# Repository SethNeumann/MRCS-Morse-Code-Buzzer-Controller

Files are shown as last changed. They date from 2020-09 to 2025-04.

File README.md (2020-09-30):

# REPO NAME: MRCS-Morse-Code-Buzzer-Controller
## License: Creative Commons Attribution-NonCommercial-ShareAlike

On many operations-oriented model railroads, particularly those which use time-table and train-order (TT&TO) or tower-based dispatching, 
there is a need to provide telephone communications between the dispatcher and the agent/operators. However, even on large model railroads
with multiple agent/operators, the physical distances between the operator positions are often insufficient to allow the operators to
reliably determine that “hey that’s my phone ringing.”

The Morse Code Buzzer Controller serves up to seven stations, tapping out each ringing station's Telegraph call sign in Railroad Morse.
An additional output can be designated an “ambience” buzzer that will randomly play one of several canned messages. These could be train
orders, news reports, or “inside jokes”

The board accepts push button inputs, stops when the phone goes off-hook (phone must have a suitable contact to provide an isolated ground 
or use the MRCS Off-Hook_Detector) and can drive loads of up to 0.5 Amp at up to 48 Volts DC.  All buzzer/sounder devices must use the same
supply.  Sounders must have have a coil resistance of greater than 40 ohms if using a 12V supply, or else use our Sounder Driver.

This version accepts 10-24 VDC from the MRCS telephone bus or a layout auxilliary supply or an external wall wart (not supplied)

The on-board Arduino Pro-Mini runs the "station buzzers" sketch by Steve Williams.  Please indicate the telegraph codes for your 
stations, unless you intend to load the sketch yourself.

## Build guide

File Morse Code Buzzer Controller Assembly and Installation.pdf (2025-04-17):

# Morse Code Buzzer Controller

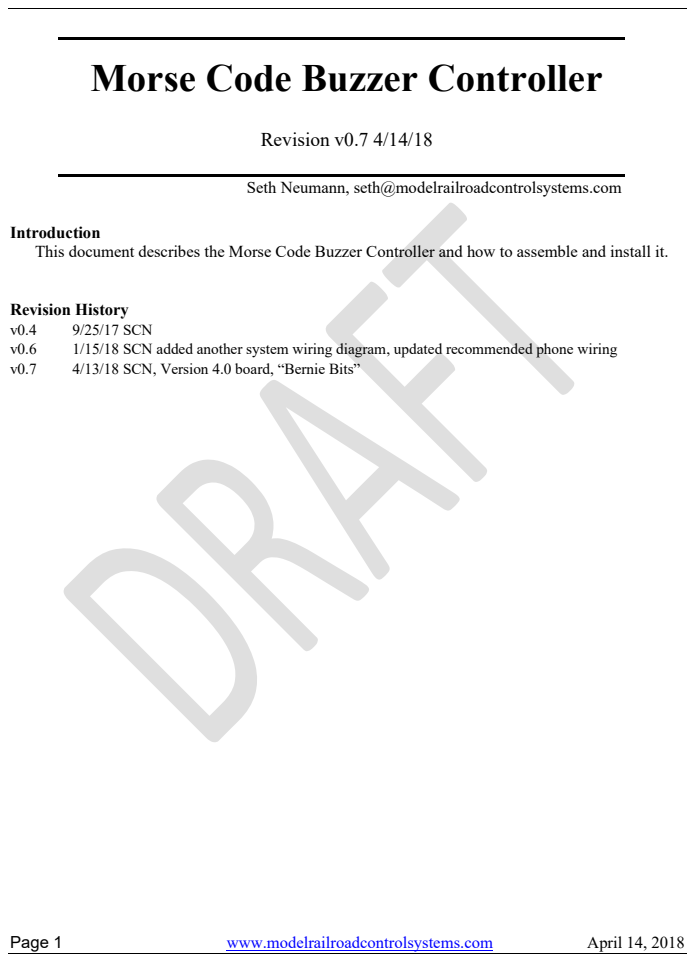
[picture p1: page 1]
Page 1; www.modelrailroadcontrolsystems.com; April 14, 2018; Revision v0.7 4/14/18; Revision History; 9/25/17 SCN; 1/15/18 SCN added another system wiring diagram, updated recommended phone wiring; 4/13/18 SCN, Version 4.0 board, “Bernie Bits”

Seth Neumann, seth@modelrailroadcontrolsystems.com

Introduction
This document describes the Morse Code Buzzer Controller and how to assemble and install it.

## Table of Contents

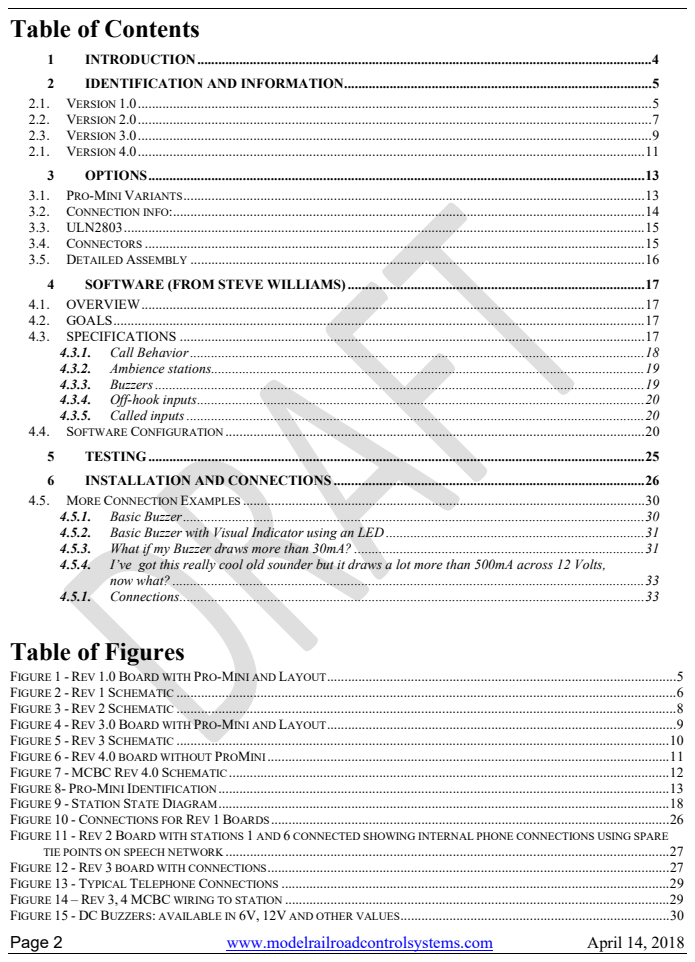
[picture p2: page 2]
Page 2; www.modelrailroadcontrolsystems.com; April 14, 2018; now what? ....................................................................................................................................... 33

1 INTRODUCTION .................................................................................................................................. 4
2 IDENTIFICATION AND INFORMATION ........................................................................................ 5
2.1. VERSION 1.0 ................................................................................................................................................... 5
2.2. VERSION 2.0 ................................................................................................................................................... 7
2.3. VERSION 3.0 ................................................................................................................................................... 9
2.1. VERSION 4.0 ................................................................................................................................................. 11
3 OPTIONS .............................................................................................................................................. 13
3.1. PRO-MINI VARIANTS .................................................................................................................................... 13
3.2. CONNECTION INFO:....................................................................................................................................... 14
3.3. ULN2803 ..................................................................................................................................................... 15
3.4. CONNECTORS ............................................................................................................................................... 15
3.5. DETAILED ASSEMBLY .................................................................................................................................. 16
4 SOFTWARE (FROM STEVE WILLIAMS) ..................................................................................... 17
4.1. OVERVIEW ................................................................................................................................................ 17
4.2. GOALS ........................................................................................................................................................ 17
4.3. SPECIFICATIONS ..................................................................................................................................... 17
4.3.1. Call Behavior .................................................................................................................................. 18
4.3.2. Ambience stations............................................................................................................................ 19
4.3.3. Buzzers ............................................................................................................................................ 19
4.3.4. Off-hook inputs ................................................................................................................................ 20
4.3.5. Called inputs ................................................................................................................................... 20
4.4. SOFTWARE CONFIGURATION ........................................................................................................................ 20
5 TESTING .............................................................................................................................................. 25
6 INSTALLATION AND CONNECTIONS ......................................................................................... 26
4.5. MORE CONNECTION EXAMPLES ................................................................................................................... 30
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

## Table of Tables

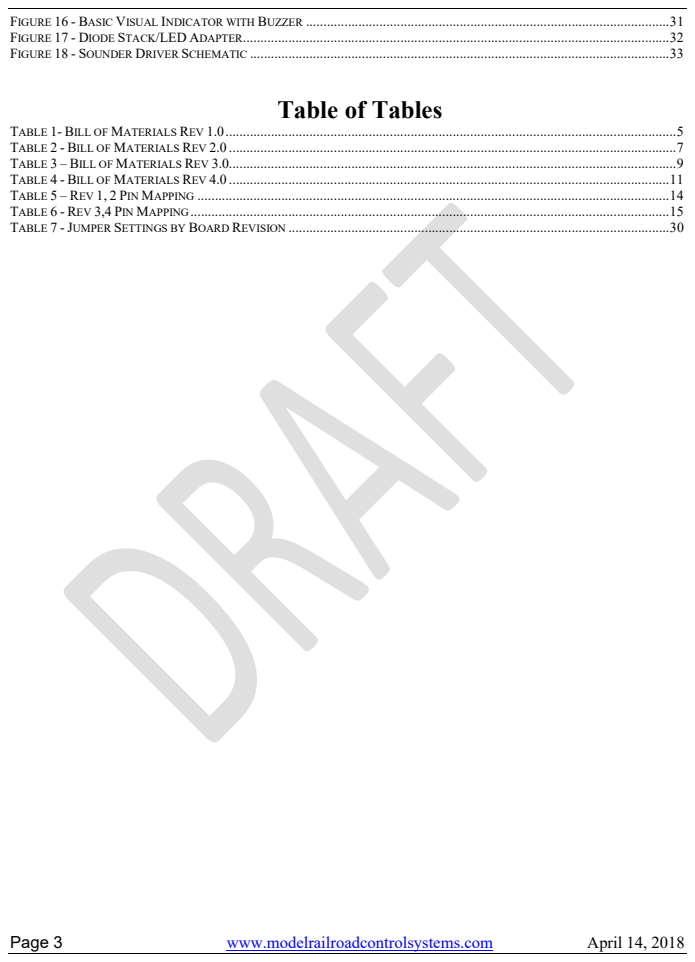
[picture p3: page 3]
Page 3; www.modelrailroadcontrolsystems.com; April 14, 2018

FIGURE 16 - BASIC VISUAL INDICATOR WITH BUZZER ........................................................................................................ 31
FIGURE 17 - DIODE STACK/LED ADAPTER .......................................................................................................................... 32
FIGURE 18 - SOUNDER DRIVER SCHEMATIC ........................................................................................................................ 33

TABLE 1- BILL OF MATERIALS REV 1.0 ................................................................................................................................. 5
TABLE 2 - BILL OF MATERIALS REV 2.0 ................................................................................................................................ 7
TABLE 3 – BILL OF MATERIALS REV 3.0................................................................................................................................ 9
TABLE 4 - BILL OF MATERIALS REV 4.0 .............................................................................................................................. 11
TABLE 5 – REV 1, 2 PIN MAPPING ....................................................................................................................................... 14
TABLE 6 - REV 3,4 PIN MAPPING ......................................................................................................................................... 15
TABLE 7 - JUMPER SETTINGS BY BOARD REVISION ............................................................................................................. 30

Page 4 | www.modelrailroadcontrolsystems.com | April 14, 2018

### 1 INTRODUCTION

This board is an Arduino Pro Mini breakout primarily designed to support Steve Williams’ “Station Buzzer” sketch. It also serves as a break out board for other applications.

- Rev 1 and 2 operate on 5 volts regulated DC, draws about 40 mA, Rev 3 uses 6-12 VDC regulated, wall wart, we recommend 7.5 – 9V to reduce the load on the on board regulator on the Pro-Mini
- Rev 1 and 2 support up to 6 stations (to use the 6th you must remove a resistor on the Pro-Mini by unsoldering)
- Each station uses two inputs and one output
- Inputs are active low* with on board pull ups, the output can sink up to .5 A at 50V DC (suitable for many sounders at 24V, but check the current draw on your sounder, you may need to use a “Sounder Driver” adapter if you expect to draw more than 0.5A)
- The Station Buzzers Sketch allows up to 7 stations to be active at any one time, but only one is buzzed at a time in order to keep the noise in the layout room reasonable and to allow operators to more accurately localize their buzzer/sounder.
- uses standard semiconductors available from Jameco and similar suppliers
- Rev 1 and 2 are based on a board that uses 6 analog capable inputs, 6 digital inputs ( or outputs) and 6 PWM capable outputs that are connected to Darlington Drivers capable of sinking up to .5A at 50V, with internal clamps. The board is also sutiable for projects such as using an analog pot to control a moderate current load with PWM (LED Lighting, Motor Control, etc). This arrangement limits the board to 6 circuits and requires modifying the Pro-Mini to use the 6th circuit.
- Rev 3 and 4 are optimized for Steve’s Station Buzzers Sketch and supports up to 7 circuits plus and an “ambience” output which randomly plays a selection of user-entered messages at random intervals. No modification of the Pro-Mini is required but there are several footprints of Pro-Minis around so be sure you use a board with enhanced Sparkfun footprint. Almost all of these are compatible on at least the first 4 circuits.

* These defaults can be changed by modifying the sketch, -- see “Software” below

All components are through-hole technology for ease of assembly and repair.

Input connection pads are standardized on .100” centers. This provides a wide range of interconnect options and components. Connection schemes include screw terminal blocks, header pin connectors (male and female), soldered right angle headers, and direct soldered wires.

Outputs are on 3.5mm connectors to handle larger wires for more current.

Power can be supplied on either a 2.1mm center positive barrel connector or a 5mm terminal block. A separate 5mm terminal block is provided for load ground and supply (if you intend to use the internal clamp diodes).

Page 5 | www.modelrailroadcontrolsystems.com | April 14, 2018

### 2 IDENTIFICATION AND INFORMATION

2.1.VERSION 1.0

Figure 1 - Rev 1.0 Board with Pro-Mini and Layout

The Revision 1.0 board has some issues with labels not aligning properly and was shipped with label tape over the board labels. These were all green. They can also be distinguished by the vertical line of 6 pads (not stuffed) next to the “FTDI header” label. These boards support up to 6 stations and, for the hackers, have start (“called” in the sketch) leads on Analog capable inputs. A separate 5mm jack is provided for output ground and for a connection to the load supply so the clamp diodes in the ULN2803 Darlington driver will protect the outputs. Using the 6th circuit requires removing the resistor for D13 from the Arduino Pro-Mini. This board uses 5VDC regulated power.

A quantity of zero denotes an alternate component or a component that may be used in a particular configuration.

Table 1- Bill of Materials Rev 1.0

Qty | Value | Device | Parts | Description | Vendor | Part #
2 .1 uF @ 50V | | C-US025-030X050 | C1, C3 | Cap, monolithic | Jameco | 25523
1 100 uF @ 50V | | CPOL-USE3.5-10 | C2 | POLARIZED CAPACITOR, American symbol | Jameco | 29962
2 | 1751264 4 PositionHeader | | J1, J2 | MKDS 1/ 4-3,5 Printklemme | Jameco | 212411
1 ARDUINO_PRO_MINI | | ARDUINO_PRO_MINI | U$2 | | eBay
1 DIODE_1N5819-B | | DIODE_1N5819-B | D1 | 1.0A SCHOTTKY BARRIER RECTIFIER | Jameco | 177965
1 Power | | CONNECTOR-DC-POWER-RA | CON3 | DC POWER JACK | Jameco | 101178
2 Power, load | | CONNECTOR-M02508-LOCK | CON4,5 | PHOENIX CONNECTOR | Jameco | 2094485
1 RAW/5V | | JUMPER-3PTH-LOCK | JP2,3,4 | | Banggood
2 12 pos 0.100 female | | 12 pos 0.100 female | JP5,6 | for arduino | Pololu | 1030
1 2 pos 0.100 female | | 2 pos 0.100 female | JP7,8 | for arduino | Pololu | 1012
1 jumper plug | | for JP 2,3,4 | jmp | power, D0, D1 | Jameco | 112432
2 Start,stop Leads | | CONNECTOR-M08LOCK | CON1,2 | Header 6 (only 6 positions used for ncb) | E-Salon
1 ULN2803 | | ULN2803A | IC1 | DRIVER ARRAY | Jameco | 34315
1 18 pin socket | | 18 pin socket | socket | socket 18 | Jameco | 112231
1 short | | M02LOCK | JP4 | Standard 2-pin 0.1 header. Use with" | Banggood
1 board 69x100 mm | | New Coded Buzzer | | Board | Seeed

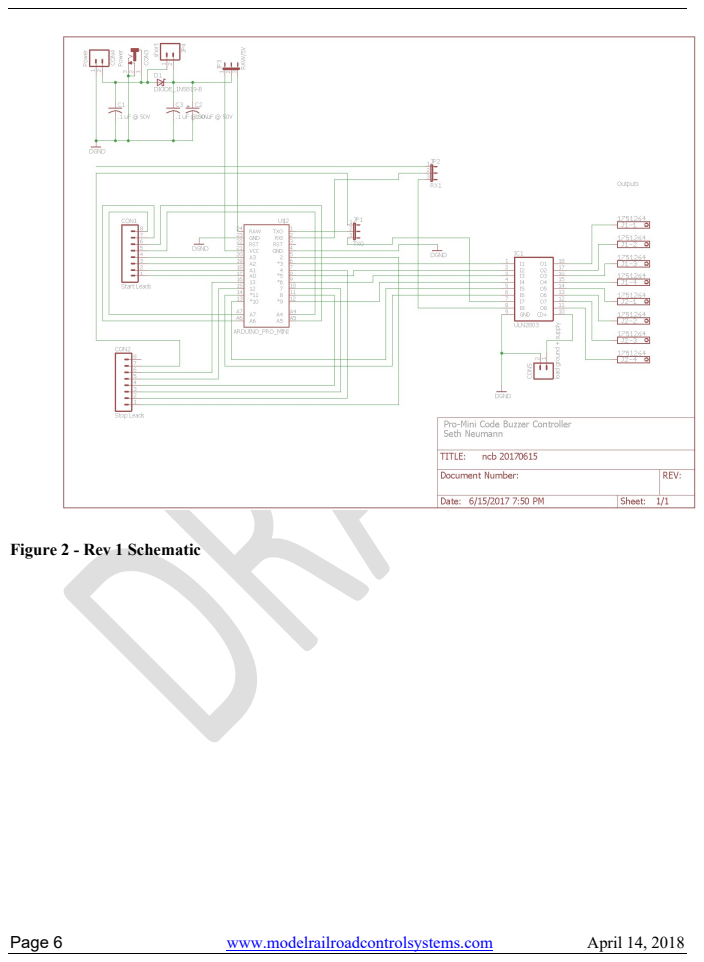
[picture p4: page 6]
Page 6; www.modelrailroadcontrolsystems.com; April 14, 2018

Figure 2 - Rev 1 Schematic

Page 7 | www.modelrailroadcontrolsystems.com | April 14, 2018

2.2.VERSION 2.0

The Revision 2.0 board was redrawn by John Plocher and the layout is optimized, and the labels and legends have been corrected. These were all on white PCBs and have 2.0 20170714 printed on the upper right. The inputs are configured the same Rev 1.0. The power connector has been rotated and placed so that you can either use the 2.1mm barrel jack or a 5mm power connector, not both. A separate 5mm jack is provided for output ground and for a connection to the load supply so the clamp diodes in the ULN2803 Darlington driver will protect the outputs. We are now shipping the Rev 3 configuration, but if you want to order this board (for an A/D project) we can make them. Using the 6th circuit, requires removing the resistor for D13 from the Arduino Pro-Mini. This board uses 5VDC regulated power.

A quantity of zero denotes an alternate component or a component that may be used in a particular configuration.

Table 2 - Bill of Materials Rev 2.0

Qty | Value | Device | Parts | Description | Vendor | Part #
1 .1 uF @ 50V | | C-US025-030X050 | C3 | Cap, monolithic | Jameco | 25523
1 100 uF @ 50V | | CPOL-USE3.5-10 | C2 | POLARIZED CAPACITOR, American symbol | Jameco | 29962
1 | 1751264 4 Position 3.5mm screw terminal | | J1, J2 | MKDS 1/ 4-3,5 Printklemme | Jameco | 212411
1 2 Position 3.5mm screw terminal
1 ARDUINO_PRO_MINI | | ARDUINO_PRO_MINI | U$2 | | eBay
1 Power | | CONNECTOR-DC-POWER-RA | CON3 | DC POWER JACK | Jameco | 101178
2 Power, load | | CONNECTOR-M02508-LOCK | CON4,5 | PHOENIX CONNECTOR | Jameco | 2094485
0 RAW/5V | | JUMPER-3PTH-LOCK | JP2,3,4 | | Banggood
2 12 pos 0.100 female | | 12 pos 0.100 female | JP5,6 | for arduino | Pololu | 1030
1 2 pos 0.100 female | | 2 pos 0.100 female | JP7,8 | for arduino | Pololu | 1012
0 jumper plug | | for JP 2,3,4 | jmp | power, D0, D1 | Jameco | 112432
2 Start,stop Leads | | CONNECTOR-M08LOCK | CON1,2 | Header 6 (only 6 positions used for ncb) | E-Salon
1 ULN2803 | | ULN2803A | IC1 | DRIVER ARRAY | Jameco | 34315
1 18 pin socket | | 18 pin socket | socket | socket 18 | Jameco | 112231
0 short | | M02LOCK | JP4 | Standard 2-pin 0.1 header. Use with" | Banggood
1 board 69x100 mm | | New Coded Buzzer | | Board | Seeed

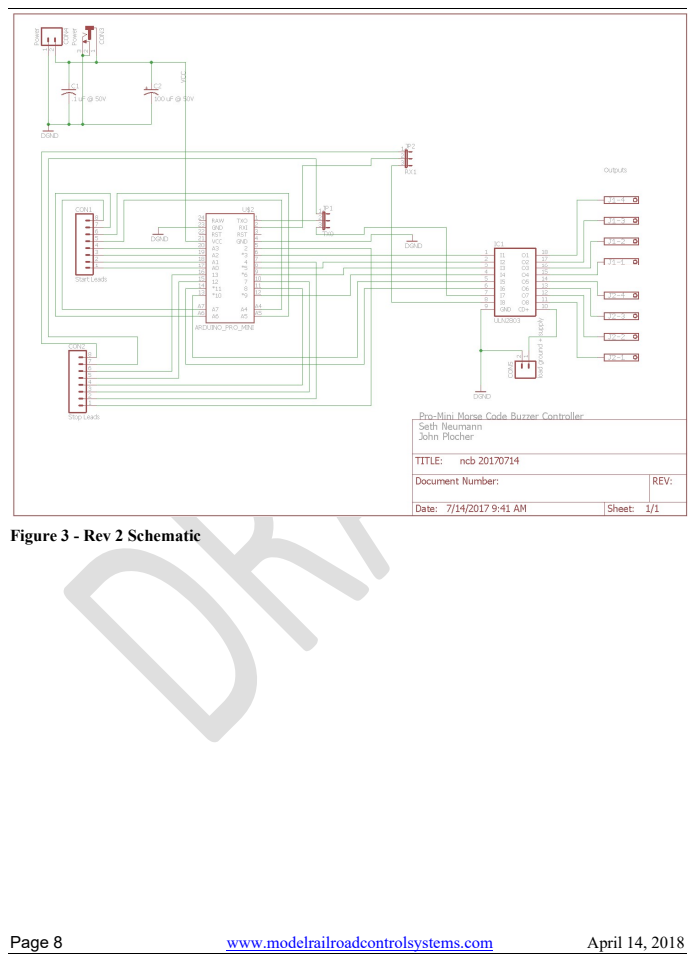
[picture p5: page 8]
Page 8; www.modelrailroadcontrolsystems.com; April 14, 2018

Figure 3 - Rev 2 Schematic

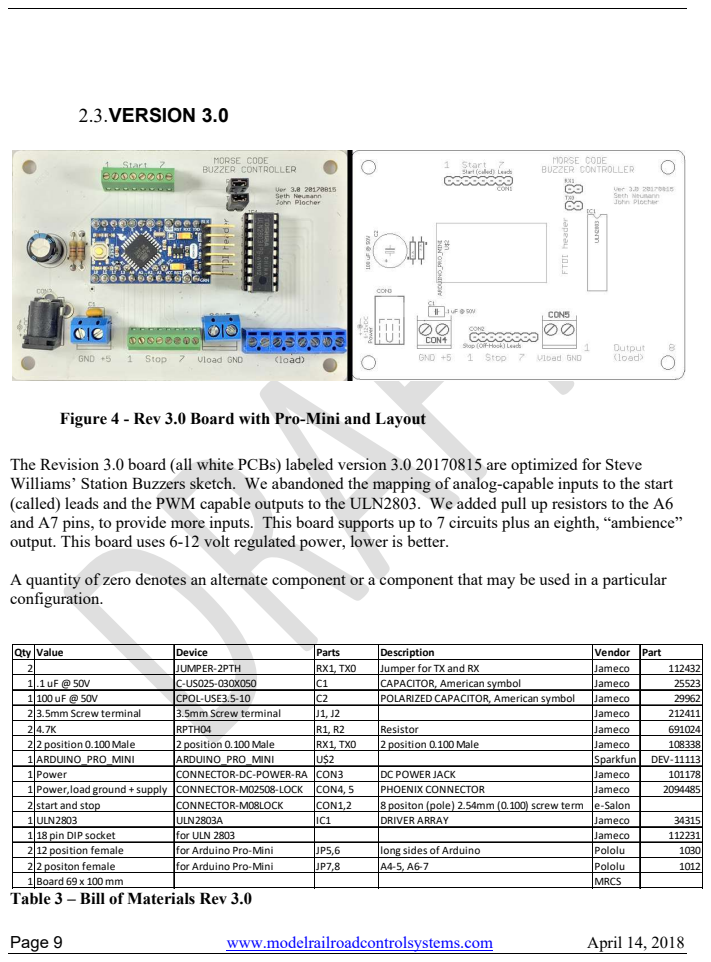
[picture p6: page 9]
Page 9; www.modelrailroadcontrolsystems.com; April 14, 2018; 2.3.VERSION 3.0

Figure 4 - Rev 3.0 Board with Pro-Mini and Layout

The Revision 3.0 board (all white PCBs) labeled version 3.0 20170815 are optimized for Steve
Williams’ Station Buzzers sketch. We abandoned the mapping of analog-capable inputs to the start
(called) leads and the PWM capable outputs to the ULN2803. We added pull up resistors to the A6
and A7 pins, to provide more inputs. This board supports up to 7 circuits plus an eighth, “ambience”
output. This board uses 6-12 volt regulated power, lower is better.

A quantity of zero denotes an alternate component or a component that may be used in a particular
configuration.

Qty | Value | Device | Parts | Description | Vendor | Part
2 | | JUMPER-2PTH | RX1, TX0 | Jumper for TX and RX | Jameco | 112432
1 .1 uF @ 50V | | C-US025-030X050 | C1 | CAPACITOR, American symbol | Jameco | 25523
1 100 uF @ 50V | | CPOL-USE3.5-10 | C2 | POLARIZED CAPACITOR, American symbol | Jameco | 29962
2 3.5mm Screw terminal | | 3.5mm Screw terminal | J1, J2 | | Jameco | 212411
2 4.7K | | RPTH04 | R1, R2 | Resistor | Jameco | 691024
2 2 position 0.100 Male | | 2 position 0.100 Male | RX1, TX0 | 2 position 0.100 Male | Jameco | 108338
1 ARDUINO_PRO_MINI | | ARDUINO_PRO_MINI | U$2 | | Sparkfun | DEV-11113
1 Power | | CONNECTOR-DC-POWER-RA | CON3 | DC POWER JACK | Jameco | 101178
1 Power,load ground + supply | | CONNECTOR-M02508-LOCK | CON4, 5 | PHOENIX CONNECTOR | Jameco | 2094485
2 start and stop | | CONNECTOR-M08LOCK | CON1,2 | 8 positon (pole) 2.54mm (0.100) screw term | e-Salon
1 ULN2803 | | ULN2803A | IC1 | DRIVER ARRAY | Jameco | 34315
1 18 pin DIP socket | | for ULN 2803 | | | Jameco | 112231
2 12 position female | | for Arduino Pro-Mini | JP5,6 | long sides of Arduino | Pololu | 1030
2 2 positon female | | for Arduino Pro-Mini | JP7,8 | A4-5, A6-7 | Pololu | 1012
1 Board 69 x 100 mm | | | | | MRCS

Table 3 – Bill of Materials Rev 3.0

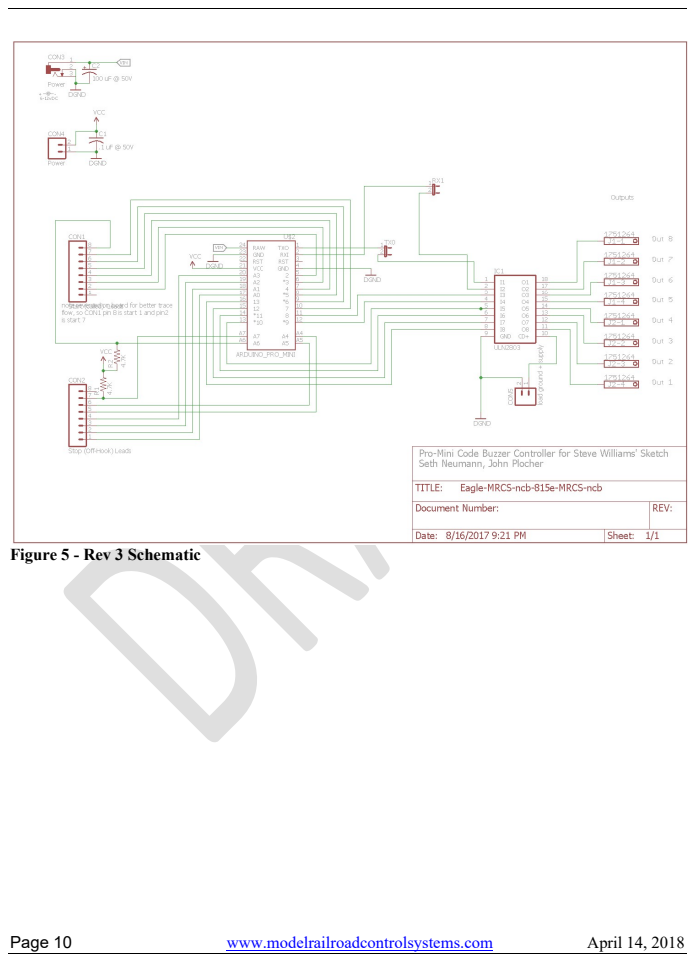
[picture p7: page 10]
Page 10; www.modelrailroadcontrolsystems.com; April 14, 2018

Figure 5 - Rev 3 Schematic

Page 11 | www.modelrailroadcontrolsystems.com | April 14, 2018

2.1.VERSION 4.0

Figure 6 - Rev 4.0 board without ProMini

The Revision 4.0 board (all white PCBs) labeled version 4.0 2018.0302 are optimized for Steve Williams’ Station Buzzers sketch. Rev 4 follows the Rev 3 mapping and adds flexibility on the Vout connector, CON4. This board uses 6-12 volt regulated power, lower is better as there is less stress on the regulator. Allow 25mA for the Arduino itself and 125mA of Vcc (of a total 150mA) is available if JP1 is set for 5V. The combination of JP1 and JP2 allow you to do any of the following:
- Source up to 125 mA of regulated 5VDC from Vout, for low voltage audible alerts such as piezo-electric sounders.
- Source the input voltage on the barrel jack to the Vout and clamp that supply voltage to the clamp diodes in the ULN2803. For example a 12V 1A supply could supply 12V buzzers (actually very little current here as only one device buzzes at a time) or even a fairly high impedance sounder (be sure to clamp inductive loads).
- Set to 5V, you can source regulated 5VDC to the Arduino by the Vout connector. DO NOT attempt to supply an input voltage higher than 5V as it will destroy the Arduino.
Qty | Value | Device | Package | Parts | Description
3 | | JUMPER-2PTH | 1X02 | JP2, RX1, TX0 | Jumpers RX, TX and Clamp
1 | | M03LOCK | 1X03_LOCK | JP1 | Header 3
1 .1 uF @ 50V | | C-US025-030X050 | C025-030X050 | C1 | CAPACITOR, American symbol
1 100 uF @ 50V | | CPOL-USE3.5-10 | E3,5-10 | C2 | POLARIZED CAPACITOR, American symbol
2 3.5mm screw term | | 3.5mm screw term | 3.5mm screw term | J1, J2 | 3.5mm screw term
2 4.7K | | RPTH04 | AXIAL-0.4-RES | R1, R2 | Resistor 1/4 Watt
1 ARDUINO_PRO_MINI | | ARDUINO_PRO_MINI | ARDUINO_PRO_MINI | U$2 | Sparkfun enhanced Style
1 Power | | CONNECTOR-DC-POWER-RA | DCJ0202 | CON3 | DC POWER JACK 2.1x5
2 Power | | CONNECTOR-M02508-LOCK | MSTB2 | CON4,5 | PHOENIX CONNECTOR
2 0.100 x 8 | | CONNECTOR-M08LOCK | 1X08_LOCK | CON1,2 | Header 8
1 ULN2803 | | ULN2803A | DIL18 | IC1 | DRIVER ARRAY
1 18 pin DIP Socket | | 18 pin DIP Socket | DIL18 | socket | 18 pin DIP Socket
2 12 pin 0.100 socket | | 12 pin 0.100 socket | 12 pin 0.100 socket | socket | long sockets for Arduino
2 2 pin 0.100 socket | | 2 pin 0.100 socket | 2 pin 0.100 socket | socket | Short sockers for A4,5 and A6,7

Table 4 - Bill of Materials Rev 4.0

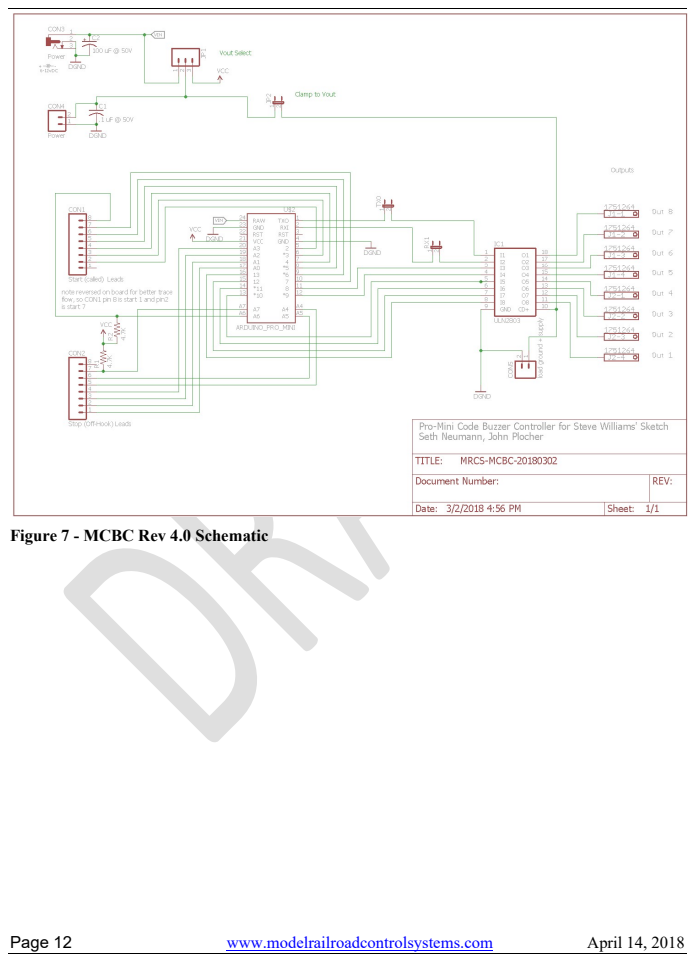
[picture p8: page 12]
Page 12; www.modelrailroadcontrolsystems.com; April 14, 2018

Figure 7 - MCBC Rev 4.0 Schematic

Page 13 | www.modelrailroadcontrolsystems.com | April 14, 2018

### 3 OPTIONS

3.1.PRO-MINI VARIANTS

The Pro-Mini was developed by Sparkfun www.sparkfun.com as a small, inexpensive alternative to Uno and Leonardo using surface mount technology and eliminating the USB port, in favor of an FTDI interface. You will need an FTDI cable or converter to program the promini. These are inexpensive and can be found at Speakfun, Adafruit and many inexpensive off-shore outlets.
There are several alternative footprints to the pro-mini. We use the revised Sparkfun version which has two rows of 12 pins along the long sides, a 6 pin FTDI header at one end and two sets of two off set pins for A4-A5 and A6-A7. If you get your Pro-Mini from Sparkfun, just go ahead and add 0.100 headers to the long sides and off set pins. One of the other designs has A4-5 in the off set position and A6-7 on the end opposite the FTDI header, the other has A4-7 on the opposite end. Be sure you’ve got the one you need. If you are not using all 7 positions you won’t need all of the A(4-7) inputs, so check your requirements and you may be able to use the other footprints.
As noted above all the analog (A0 through A7) are used as inputs. Since these inputs are capable of A to D conversion, I’ve kept them separate for use in other projects on Rev 1 and 2. The outputs D3,5,6,9,10 and 11 are PWM capable, and since PWM is an output function, I’ve kept them together on Rev 1 and 2. The stop inputs use the non-PWM digital pins remaining starting with D2 on Rev 1 and 2 boards. D0 and D1 are Rx and TX respectively and they are connected by three position jumpers to either outputs six and seven or stop lines 6 and seven or they can be left open if not otherwise used. The jumpers should be removed while programming. On Rev 3 boards the mapping has changed (see configuration below) to allow up to 7 circuits.

Figure 8- Pro-Mini Identification

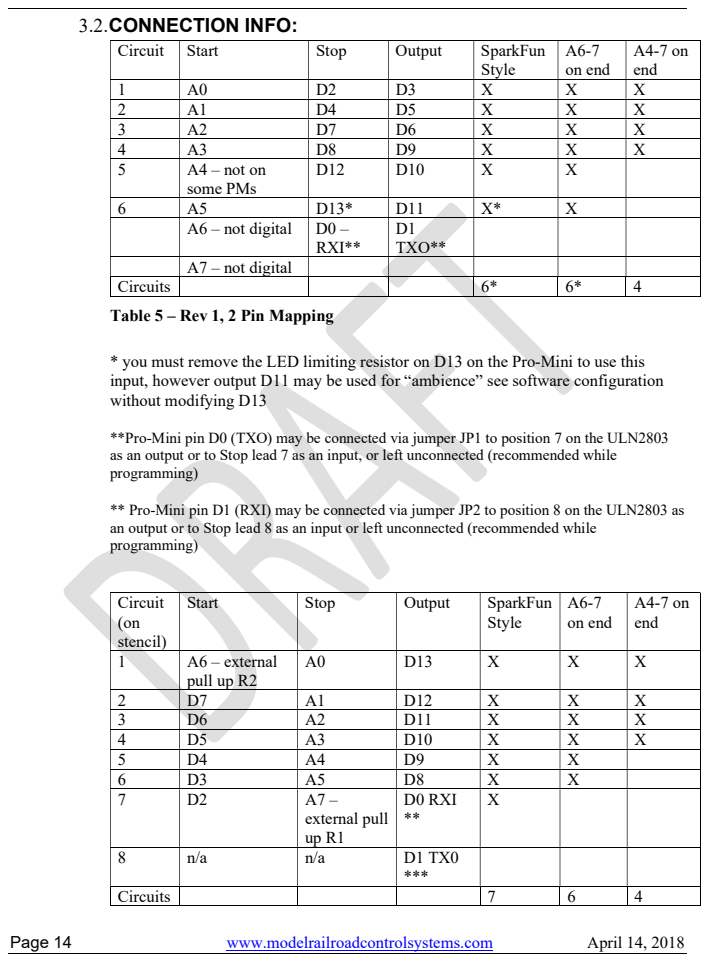
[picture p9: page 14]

Circuit | Start | Stop | Output | SparkFun Style | A6-7 on end | A4-7 on end

1 | A0 | D2 | D3 | X | X | X
2 | A1 | D4 | D5 | X | X | X
3 | A2 | D7 | D6 | X | X | X
4 | A3 | D8 | D9 | X | X | X
5 A4 – not on | some PMs | D12 | D10 | X | X

A6 – not digital | D0 – RXI** | D1 TXO**

A7 – not digital

Circuits | | | | 6* | 6* | 4

Table 5 – Rev 1, 2 Pin Mapping

* you must remove the LED limiting resistor on D13 on the Pro-Mini to use this
input, however output D11 may be used for “ambience” see software configuration
without modifying D13

**Pro-Mini pin D0 (TXO) may be connected via jumper JP1 to position 7 on the ULN2803
as an output or to Stop lead 7 as an input, or left unconnected (recommended while
programming)

** Pro-Mini pin D1 (RXI) may be connected via jumper JP2 to position 8 on the ULN2803 as
an output or to Stop lead 8 as an input or left unconnected (recommended while

Circuit (on stencil) | Start | Stop | Output | SparkFun Style | A6-7 on end | A4-7 on end

1 A6 – external | pull up R2 | A0 | D13 | X | X | X

2 | D7 | A1 | D12 | X | X | X
3 | D6 | A2 | D11 | X | X | X
4 | D5 | A3 | D10 | X | X | X
5 | D4 | A4 | D9 | X | X
6 | D3 | A5 | D8 | X | X
7 | D2 | A7 – external pull up R1 | D0 RXI ** | X

Circuits | | | | 7 | 6 | 4

Page 15 | www.modelrailroadcontrolsystems.com | April 14, 2018

Table 6 - Rev 3,4 Pin Mapping

**Pro-Mini pin D0 (TXO) may be connected via jumper JP1 to position 7 on the ULN2803 as an output or to Stop lead 7 as an input, or left unconnected (recommended while programming)

*** Pro-Mini pin D1 (RXI) may be connected via jumper JP2 to position 8 on the ULN2803 as an output or to Stop lead 8 as an input or left unconnected (recommended while programming). It is recommended that you use TXO if you want to employ the “ambience” function.

3.3.ULN2803

The ULN2803 is a high current driver that can sink up to 0.5A at up to 50V on each output. We included it because the lead users wanted to drive telegraph sounders, which operate at 24-48 volts, and the Pro-Mini is limited to 5V (and 25 mA). If you will only be driving logic level loads, you can omit the ULN2803 and wire across the pins for the socket. If you are using a Rev 1 or 2 board for motor or high current LED control, you’ll want to use the ULN2803. We recommend socketing the ULN2803 because it lives in a rough neighborhood and may need replacement.

3.4.CONNECTORS

- The input connectors are on 0.100 centers (staggered slightly to hold the connectors in place during assembly). While our standard connector is the 0.100 screw terminal, you may substitute any other 0.100 connector you prefer. If ordering an assembled and tested unit from MRCS and you would prefer a different connector, please contact us at sales@modelrailroadcontrolsystems.com and indicate your preference and we’ll provide a quotation.
- Output connectors are 3.5mm screw terminals. Again you can substitute any 3.5mm pitch connector.
- We provided a 2.1 mm, center positive, barrel jack for power, Rev 1 and 2 use 5V, Rev 3 and

### 4 use 6-12 volts. Be careful and check the output of your power supply, overvoltage will

kill the Pro-Mini. The 5mm pitch screw terminal block parallels the barrel jack (Rev1,2) but in Rev 3 the 5V is the output of the Pro-Mini’s regulator. In Rev 4 the 5V is replaced by a Vout pin which can be jumper selected to either 5V from the regulator (keep your loads to a total of 100 mA) or the voltage from the barrel jack.

- The last connector is a 5mm screw terminal for referencing the output loads (buzzer, sounder etc.) Connect the ground to the ground of the supply powering the outputs (don’t worry about this if running low current/low voltage buzzers off the Morse Code Buzzer Controller’s supply). Connect the positive side of the load supply to the screw marked “LD” or “LOAD” This provides a reference for the clamp diodes in the ULN2803 that protects it from inductive spikes.

Page 16 | www.modelrailroadcontrolsystems.com | April 14, 2018

3.5.DETAILED ASSEMBLY
[ ] All of the components are through-hole technology with wire leads. A useful tool is a lead bender for forming the leads at 90 degrees for easy insertion into the pad holes. Start with inserting the lower height components. The general rule is install the lowest components first, working towards components that are higher off the board. This enables you to support the low components as you solder them.

[ ] Resistors, Diodes
[ ] Install Resistors R1 and R2 (Rev 3 only) on the center left of the boards. Try to keep the gold tolerance band on the same side for easier reading of values.
[ ] Install diodes D1 (Rev 1.0 only). Observe polarity – band towards edge of board.

[ ] Monolithic Capacitors

[ ] Install C1,C3 (C3 on Rev 1.0 only) on left edge of board

[ ] IC Socket (if you are using the ULN2803)
[ ] Socket for IC1 – notch in socket pointing up

[ ] Electrolytic Capacitors
[ ] Install C2 last as it is the highest component on the board. Observe polarity: stripe to the right.

[ ] Arduino Sockets – these come in various heights, so compare height off board with other components.

[ ] Option Headers
[ ] Install JP1,2,3,4 (Rev 1.0, Rev 4.0 ), JP1,2 (Rev 2.0, Rev 3.0),

[ ] Screw Terminals and Power Jack
[ ] Install Con3 (2.1 mm barrel jack) unless you will not be using a 2.1mm plug to power your Morse Code Buzzer Controller
[ ] Install Con1 and Con2
[ ] Install Con4 unless you will be using Con3
[ ] Install Con5

[ ] Electronics

[ ] Install the ULN2803 if you are planning to use high current or high voltage (>5V) loads [ ] Install the Pro-Mini

[Pro-Mini]

Most pro-Minis come with male headers, if not you will need to supply them. I use the board as a fixture to hold the headers in place. Just put the headers into the socket and then gently wiggle the Pro-Mini so it sits down tight and solder the end pins on each header. Then check for alignment, it’s easy to adjust with just one pin on each end soldered, a quick re-melt will do.

Page 17 | www.modelrailroadcontrolsystems.com | April 14, 2018

### 4 SOFTWARE (FROM STEVE WILLIAMS)

### 4.1. OVERVIEW

On many operations-oriented model railroads, particularly those which operate under a timetable and train-order (TT&TO) or tower-based dispatching system, there is a need to provide telephone communications between the dispatcher and the agent/operators. However, even on fairly large model railroads with multiple agent/operators, the physical distances between the operator positions are often insufficient to allow the operators to reliably distinguish that “hey that’s my phone ringing.”

This document describes the design of the “station_buzzzers” Arduino script which controls the buzzers on a model railroad telephone system to play the called station’s timetable station call-sign in American Railroad Morse code, and to cycle among the called stations so that only one buzzer is sounding at a time. Model Railroad Control Systems has developed a companion “Morse Code Buzzer Board” which provides convenient connections to an Arduino Pro-Mini running the station_buzzers sketch.

### 4.2. GOALS

1. Provide separate “buzzer pins” for each station. Each pin can be made active HIGH or active LOW as needed depending on the external buzzer driver circuits used. The Morse Code Buzzer Controller uses an active high output to activate it’s Darlington output which provides a ground to operate a load of up to 0.5A at up to 50V.

### 2. Provide support for “ambience” buzzers that will randomly play one of several canned

messages. These could be train orders, news reports, or “inside jokes”.
3. Provide separate “answered” inputs for each station with individual control of the active HIGH or LOW level for the input. The Morse Code Buzzer Controller assumes a low input, but you can change it in this sketch.
4. Provide separate “called” input pins for each with individual control of the HIGH or LOW.
a. Each “called” input should also have individual selection between “momentary” versus “continuous”mode. For “continuous” mode, the station’s call-sign will continue to play until either the station is answered or the caller hangs up. For “momentary” stations, the station will start ringing after a momentary button press and continue ringing until answered or after a timeout. The Morse Code Buzzer Controller assumes a low input, but you can change it in this sketch.
5. Only allow one station buzzer to play at a time. When multiple stations are being called simultaneously, cycle through them playing each station’s call-sign with a couple of seconds delay between the end of one call-sign and the beginning of the next. This provides temporal as well as spatial separation of the station call-signs.

### 4.3. SPECIFICATIONS

Configuration of the list of station's, their call-signs, and operating modes will be done through a C++ structure array.

Page 18 | www.modelrailroadcontrolsystems.com | April 14, 2018

### 4.3.1. Call Behavior

The basic call flow for a single station is shown in the flow chart below.

Figure 9 - Station State Diagram

The states that each station runs through are:

IDLE -- both called and off_hook are deasserted

RING_WAITING -- the station has been called, but not yet answered. Stations enter this state before they are selected to ring. Stations entering RING_WAITING state set their last_ring_millis value to the current millis(), but stations entering from IDLE subtract 60 seconds so that they will look artificially old to the “selected_to_ring” logic

RING_PLAYING -- the station has been called and not answered and has been selected to ring. Only one station can be in the RING_PLAYING state at a time, and typically it will stay there until the Morse code for the station call-sign finishes playing one time. The selection of which station should ring is done by choosing the station which has been in the RING_WAITING state the longest.

TALKING -- the station is off-hook. We don't make a distinction between whether we got here directly from IDLE (station-initiated call) or from one of the RING_WAITING or RING_PLAYING states. For “momentary” stations, immediately upon entering TALKING, the called input is cleared and the station will transition to HANGUP_WAIT state.

Page 19 | www.modelrailroadcontrolsystems.com | April 14, 2018

HANGUP_WAIT -- one or the other sides has hung up and we are waiting for both sides to hang up.

The same basic flow applies to stations that use either “momentary” or “continuous” called inputs. All that is different is how the various “called” and “off_hook” methods behave.

### 4.3.2. Ambience stations

The sketch will also support defining one or more “ambience” stations. These are intended to be used for extra “audio candy” in the layout room. Each “ambience” station has a pointer to a table of message strings, and will randomly play one these messages each time it wakes up. The strings themselves will be stored in the Arduino’s flash (program) memory to allow a larger number of longer messages than just the typical one or two character station call-signs. The wake up interval will be randomly selected between a minimum and maximum interval.

Upon entry to IDLE state, an ambience station will choose the next string to play and the time in millis() at which to play it. When the designated time comes, the ambience station will transition to RING_WAITING. The choose_next_ringer selection logic will only allow an ambience station to transition RING_WAITING -> RING_PLAYING if all “regular” stations are in state IDLE.

If the sketch defines more than one ambience station, each ambience station will individually choose its random start time and which message to play next. If a another ambience station is playing when this station becomes ready to play, the sketch will let the first station’s message complete before starting the second. Internally, this is done through the normal IDLE -> RING_WAITING -> RING_PLAYING -> IDLE state sequence.

Any regular station leaving state IDLE (being called or going off-hook) will immediately force any ambience station in state RING_PLAYING back to state IDLE, terminating the current ambience message, resetting the random timers and making a new message choice. The thinking here is that the ambience buzzer may be playing a longer message that could distracting, so it is better to shut it off immediately.

Similarly, if any of the regular stations leaves state IDLE while any ambience station(s) are in RING_WAITING state, the ambience stations will stay RING_WAITING until all of the regular stations return to state IDLE (i.e. all calls are ended) before becoming eligible to play. It seems appropriate to give force the next ringer selection logic to wait a bit longer before allowing the ambience to resume, so there will be a separate timer to keep “ambience” messages farther apart.

### 4.3.3. Buzzers

We have used this sketch to drive a variety of sound-generating hardware from piezo-electric buzzers to relay-based telegraph sounders. In a quiet room, it may be possible to drive a piezo transducer directly from an active-low Arduino output. But in most cases an external driver circuit is needed to protect the Arduino from the speaker power supply voltage or to provide more “oomph” for the sound. For this reason, we want individual selection of active HIGH or LOW on each buzzer circuit. The MRCS “Morse Code Buzzer Board” outputs

Page 20 | www.modelrailroadcontrolsystems.com | April 14, 2018

provide up to 500mA at up to 50 Volts via Darlington drivers, which is more than adequate for most vintage sounders, and it works with piezo-electric and mechanical buzzers as well.

### 4.3.4. Off-hook inputs

The local hook switch in most telephones is more suited being wired so that the Arduino input is floating when on-hook and grounded when the handset is off-hook. But given the variety of cannibalized phone gear which might be deployed on a model railroad phone system, there is no reason not to support individual selection of active HIGH or LOW on each “off-hook” input.

### 4.3.5. Called inputs

Most commonly, the “called” inputs will be active LOW normally open connections -- the calling station will pull the “called” input to ground, and the Arduino’s internal pull-up resistor will float the input HIGH when not called. But again, for flexibility, each input will have individual control of the “called” state HIGH or LOW.

In addition, there are two main styles of telephone systems in use for model railroads: multi-line systems based on office style PBX gear or simpler single party-line systems. For multi-line systems, it is common to have the called station ring either until it is answered or until the calling party hangs up.

On party line systems, it is often simpler to have a set of momentary station call buttons on the dispatcher’s desk. When the button is pressed, the corresponding station begins to to ring, and continues to ring until it is either answered or a time limit (say 2 minutes) is reached.

We will support selection of the “momentary” or “continuous” behavior on a per-line basis. Each station will have an individual timeout value. Zero will indicate a “continuous” style station that rings until the “called” input goes inactive or the “answered” goes active. Non-zero will give a programmable ring duration for “momentary” stations.

4.4.SOFTWARE CONFIGURATION
Open the file station_buzzers.ino in Arduino IDE (Integrated Development Environment) and the tab STATION_BUZZERS. This file is available on Steve’s GitHub page: https://github.com/stevew1154/station_buzzers

The following is part of the sketch from lines 40 – 157, the Rev configuration starts at line 76. The active entry for A6, A7 must be ANALOG_LOW, Note ANALOG_LOW has a un under-bar in it.

// stations

//

// This table defines the stations on the layout.

//

// Normal stations have level-sensitive “called” inputs, and will continue ringing until either

Page 21 | www.modelrailroadcontrolsystems.com | April 14, 2018

// answered or until the caller hangs up. To define a “normal” station, set the station_type to

// STATION_NORMAL, and define the “buzzer”, “called” and “off_hook” pins. The timeout value is

// ignored.

//

// Momentary stations are defined by setting station_type to STATION_MOMENTARY, set the buzzer,

// called, and answered pins. The timeout value should specify the timeout in seconds. If set to

// zero, the station will ring forever or until answered.

//

// To define an “ambience” station, set the “station_type” to STATION_AMBIENCE, and the”called” and

// “off_hook” pins to -1. The timeout will then define a “base” time between random ambience

// messages. The sketch will pick a random interval between 2/3 and 4/3 of this base time. It really

// doesn’t matter what you set the “station_code” to, as that field will only show up in debug

// messages.

//

// Use of Arduino “analog” pins

// ============================

//

// On most Arduino variants, the analog input pins A0-A5 are also fully capable of being digital

// input or output pins. However, the A6 and A7 pins are a mixed bag. On the Leonardo and other

// ATMEGA 32u4 based boards, A6 and A7 are muxed with other digital input pins so you probably

// don’t want to use them by the names A6/A7.

//

// On the Uno, Mini, Nano and probably most other ATMEGA-328P variants A6 and A7 are distinct

// pins, but lack any sort of digital hardware, and therefore can only be used as analog

// inputs. This sketch will allow you to use A6 and A7 of the 328-based Arduinos as either “called”

// or “off_hook" inputs, but you must specify "active" as ANALOG_LOW or ANALOG_HIGH instead of LOW

// or HIGH. Also, your circuit must provide an external pull-up (ANALOG_LOW) or pull-down

// (ANALOG_HIGH) resistor. I.e. if your called switch connects pin A6 to ground, specify it as

Page 22 | www.modelrailroadcontrolsystems.com | April 14, 2018

// A6,ANALOG_LOW in the table and provide an external pull-up resistor (1K Ohm should work well).

// MRCS Buzzer Board rev 2

//

// The second-generation buzzer board supports 7 stations plus an ambience buzzer

#undef MRCS_REV2_TABLE

[This is the standard Rev 3 table, make this line above “#DEFINE”, note you will need to change the pin mapping and use your station codes instead of AA, BB etc.]
#ifdef MRCS_REV2_TABLE

const struct Station_Info stations[] = {

// buzzer called off_hook timeout station

// station_type, pin,active, pin,active, pin,active, seconds, code

{ STATION_MOMENTARY, 13, HIGH, A0, LOW, A6, ANALOG_LOW, 0, "AA" },

{ STATION_MOMENTARY, 12, HIGH, A1, LOW, 7, LOW, 0, "BB" },

{ STATION_MOMENTARY, 11, HIGH, A2, LOW, 6, LOW, 0, "CC" },

{ STATION_MOMENTARY, 10, HIGH, A3, LOW, 5, LOW, 0, "DD" },

{ STATION_MOMENTARY, 9, HIGH, A4, LOW, 4, LOW, 0, "EE" },

{ STATION_MOMENTARY, 8, HIGH, A5, LOW, 3, LOW, 0, "FF" },

{ STATION_MOMENTARY, 0, HIGH, A7, ANALOG_LOW, 2, LOW, 0, "GG" },

// This demonstrates an "ambience" station which will buzz one of the random ambience messages

// at a random time between 2/3 and 4/3 of the "timeout_sec". This station doesn't need

// "answered" or "called" pins so they are set to -1. Also, the "station code' is ignored.

{ STATION_AMBIENCE, 1, HIGH, -1, LOW, -1, LOW, 60, "MM" },

};

#endif

// David Parks Cumberland West

//

// This layout has 5 "normal" stations that ring until answered or until the caller hangs up

#define DAVID_PARKS_TABLE

#ifdef DAVID_PARKS_TABLE

const struct Station_Info stations[] = {

// buzzer called off_hook timeout station

// station_type, pin,active, pin,active, pin,active, seconds, code

{ STATION_NORMAL, 8, HIGH, A0, LOW, 2, LOW, 0, "ND" }, // Viaduct

{ STATION_NORMAL, 9, HIGH, A1, LOW, 3, LOW, 0, "GE" }, // Evitts

Page 23 | www.modelrailroadcontrolsystems.com | April 14, 2018

{ STATION_NORMAL, 10, HIGH, A2, LOW, 4, LOW, 0, "KY" }, // Keyser

{ STATION_NORMAL, 11, HIGH, A3, LOW, 5, LOW, 0, "CO" }, // McKenxie

{ STATION_NORMAL, 12, HIGH, A4, LOW, 6, LOW, 0, "P" }, // Piedmont

// This demonstrates an "ambience" station which will buzz one of the random ambience messages

// at a random time between 2/3 and 4/3 of the "timeout_sec". This station doesn't need

// "answered" or "called" pins so they are set to -1. Also, the "station code' is ignored.

{ STATION_AMBIENCE, 13, HIGH, -1, LOW, -1, LOW, 60, "DS" }, // Dispatcher

};

#endif

// Dave Adams D&RGW

//

// This layout has 6 momentary stations, and no ambience buzzer. It is built on the MRCS Morse Buzzer

// board v1.0, using an Arduino Pro Mini (Atmel 328P), and in order to use pin 13 as an input for "RO",

// Seth Neumann removed the built-in LED on D13.

//

// This sketch should work equally well on a Nano or a Leonardo with the same caveat: D13 is hard to

// use as an input without either removing the on-board LED circuit or adding a pull-up resistor.

#undef DAVE_ADAMS_TABLE

#ifdef DAVE_ADAMS_TABLE

const struct Station_Info stations[] = {

// buzzer called off_hook timeout station

// station_type, pin,active, pin,active, pin,active, seconds, code

{ STATION_MOMENTARY, 11, HIGH, A0, LOW, 2, LOW, 30, "DW" }, // West Durango

{ STATION_MOMENTARY, 10, HIGH, A1, LOW, 4, LOW, 30, "HF" }, // Hesperus

{ STATION_MOMENTARY, 9, HIGH, A2, LOW, 7, LOW, 30, "CA" }, // Cima Summit

{ STATION_MOMENTARY, 6, HIGH, A3, LOW, 8, LOW, 30, "MX" }, // Mancos

{ STATION_MOMENTARY, 5, HIGH, A4, LOW, 12, LOW, 30, "DJ" }, // Dolores

{ STATION_MOMENTARY, 3, HIGH, A5, LOW, 13, LOW, 30, "RO" }, // Rico

};

#endif

const int num_stations = sizeof(stations) / sizeof(stations[0]);

Page 24 | www.modelrailroadcontrolsystems.com | April 14, 2018

// The messages played by the ambience sations are defined here. We are playing Arduino AVR tricks

// here to place the strings themselves in the Arduino's larger program memory.

//

// You can add as many messages as you need, limited only by the code space in your Arduino. Adding

// a message is a two-step process -- first, you need to add a declaration for the string itself

// like the declaration for "ambience_00" below. Simply copy/paste the last string and bump the

// number. Then you have to add the new string to the "ambience_messages" array.

const char ambience_00[] PROGMEM = "OS No 2 by ND at 14:45";

const char ambience_01[] PROGMEM = "DS GE Copy 3 West";

const char ambience_02[] PROGMEM = "Check box 13, the dispatcher is an idiot.";

const char * const ambience_messages[] PROGMEM = {

ambience_00, ambience_01, ambience_02,

};

const int num_ambience_messages = sizeof(ambience_messages) / sizeof(ambience_messages[0]);

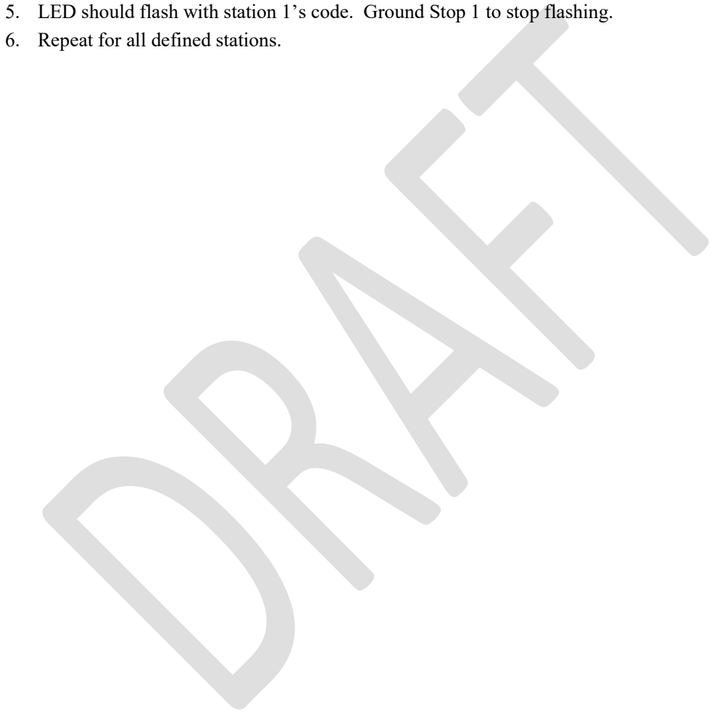
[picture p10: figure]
6. Repeat for all defined stations.

Page 25 | www.modelrailroadcontrolsystems.com | April 14, 2018

### 5 TESTING

Testing your Morse Code Buzzer Controller is quick and simple:

### 1. Mount the board securely on standoffs or in a piece of 2.75” DINRail

2. Apply 5VDC (Rev 1.0, 2.0) or a 6-12 V regulated supply (Rev 3.0) regulated power with a 2.1mm center positive plug to Con3
3. Connect an LED with 470 ohms in series from your supply voltage to output 1 (cathode – the short lead) to output 1.
4. Apply a ground momentarily to input 1.
5. LED should flash with station 1’s code. Ground Stop 1 to stop flashing.

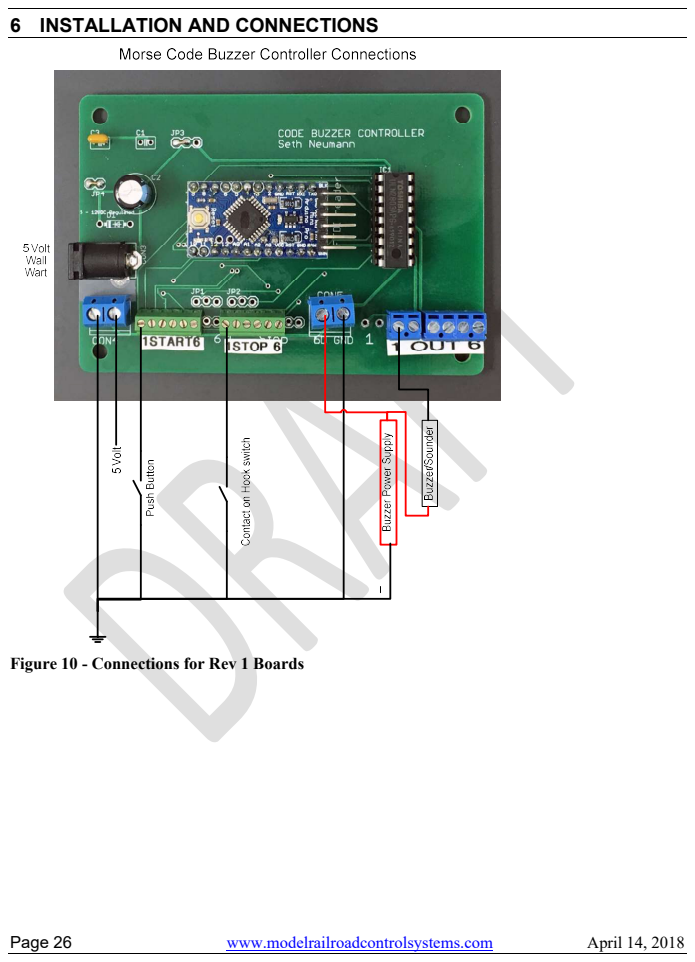
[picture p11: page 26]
Page 26; www.modelrailroadcontrolsystems.com; April 14, 2018

6 INSTALLATION AND CONNECTIONS

Figure 10 - Connections for Rev 1 Boards

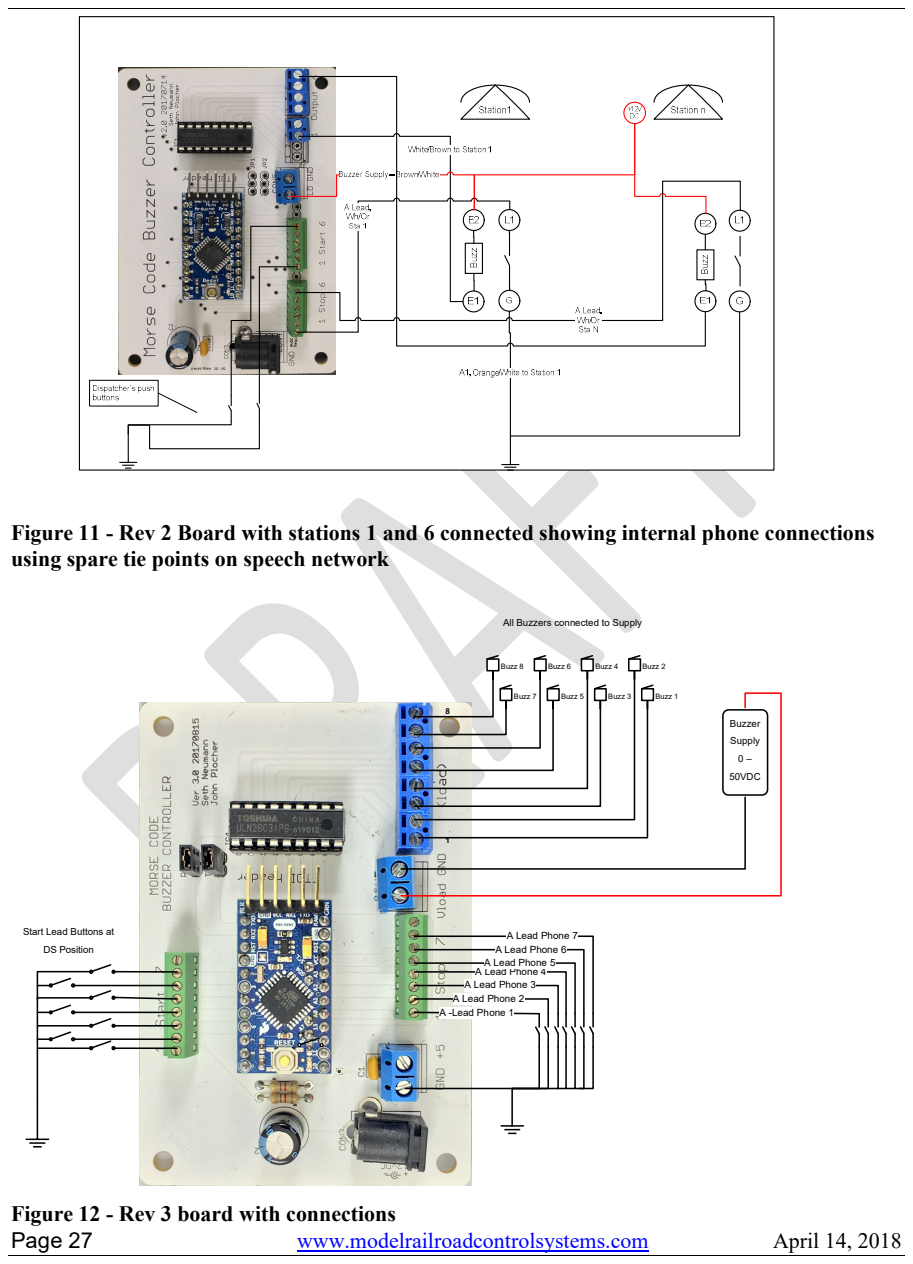
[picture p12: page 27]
Page 27; www.modelrailroadcontrolsystems.com; April 14, 2018; 8 Start Lead Buttons at DS Position; A -Lead Phone 1 A Lead Phone 2 A Lead Phone 3 A Lead Phone 4 A Lead Phone 5 A Lead Phone 6 A Lead Phone 7; Buzz 8; Buzz 6; Buzz 4; Buzz 2 Buzz 7; Buzz 5; Buzz 3; Buzz 1 All Buzzers connected to Supply; Buzzer Supply 0 –; 50VDC

Figure 11 - Rev 2 Board with stations 1 and 6 connected showing internal phone connections
using spare tie points on speech network

Figure 12 - Rev 3 board with connections

Page 28 | www.modelrailroadcontrolsystems.com | April 14, 2018

Rev 4.0

Rev 4 follows the Rev 3 mapping and adds flexibility on the Vout connector, CON4. This board uses 6-12 volt regulated power, lower is better as there is less stress on the regulator. Allow 25mA for the Arduino itself and 125mA of Vcc (of a total 150mA) is available if JP1 is set for 5V. The combination of JP1 and JP2 allow you to do any of the following:
- Source up to 125 mA of regulated 5VDC from Vout, for low voltage audible alerts such as piezo-electric buzzers.
- Source the input voltage on the barrel jack to the Vout and clamp that supply voltage to the clamp diodes in the ULN2803. For example a 12V 1A supply could supply 12V buzzers (actually very little current here as only one device buzzes at a time) or even a fairly high impedance sounder (be sure to clamp inductive loads).
- Set to 5V, you can feed regulated 5VDC to the Arduino by the Vout connector. DO NOT attempt to supply an input voltage higher than 5V as it will destroy the Arduino.

General Considerations for all boards and connections:
- Input voltages must be no more than 5 volts, so try to use “dry” contacts (contacts with no other connections.) When using CAT5 wire, I use the telephone convention of WHITE/ORANGE is the switched input lead (ground when phone is off hook), and Orange/White is connected to system ground.
- If you are sharing the contact with some other function, ground must be tied to the board ground and I recommend using a diode (1N4001 or equivalent) to isolate the legs. If your existing circuit has off hook showing 5V, you can reverse the sense of the input (except for A6 and A7) in the configuration table in the sketch. A6 and A7 have pull up resistors, so this isn’t a good trick for circuits 6 and 7.
- The outputs provide a ground (sink) when the output is on. Each output can ground a load of up to 0.5A at up to 50V. The load ground must be connected to the ground terminal on CON5 and the Supply output must be connected to Load (LD) on CON5 in order to use the internal clamp diodes on the ULN2803. This critical when driving inductive loads such as sounders, relays and motors. I use the telephone convention of BROWN/WHITE to Buzzer Supply and WHITE/BROWN to the ground side of the buzzer (the side connected to the Morse Code Buzzer Controller).
- Interfaces for non-compliant inputs. If you need to use a start (called) or stop (off-hook) input that is either greater than 5V with respect to the Morse Code Buzzer Controller’s ground or negative (traditional Key Telephone System), the you can use either a relay or an opto-isolator to provide an isolated input to the MCBC. There is a wide selection of both available. For relays, we like the OMRON G5V-2-H-DC24 or equivalent, you should be able to find this from inexpensive off-shore sources for around $1.00, connect one side of the coil to the -24V supply and the other to the “A” lead. If you want use an opto-isolator, the venerable 4N25 is a good start, for about $0.25, put it in series with a 2.2 K ohm resistor from -24 to the “A” lead and connect the output from ground to the MCBC input.

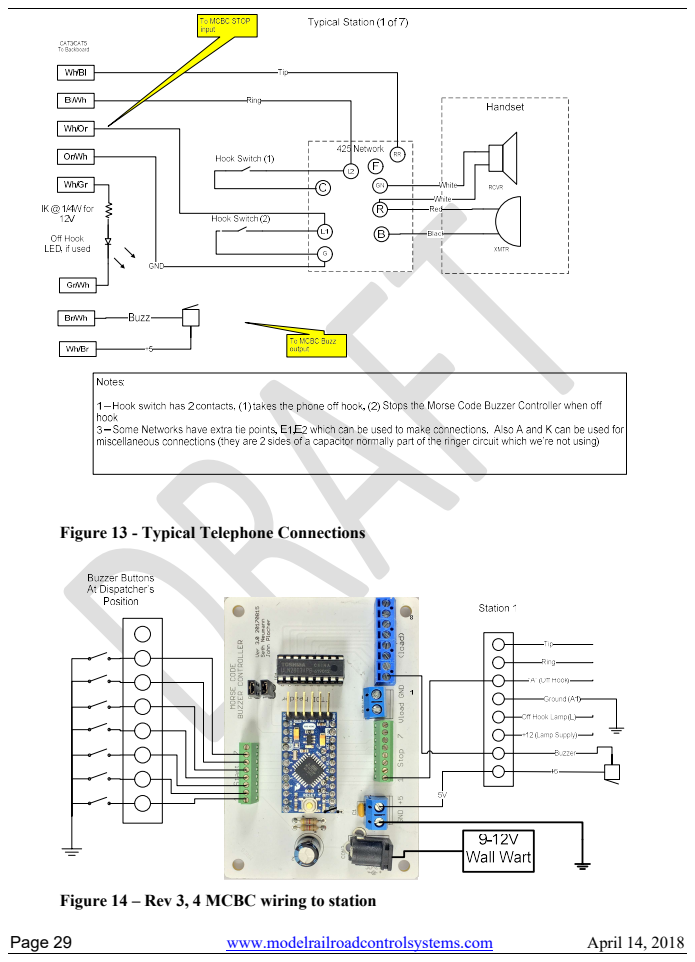
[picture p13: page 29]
Page 29; www.modelrailroadcontrolsystems.com; April 14, 2018

Figure 13 - Typical Telephone Connections

Figure 14 – Rev 3, 4 MCBC wiring to station

Page 30 | www.modelrailroadcontrolsystems.com | April 14, 2018
Revision | JP1 | JP2 | JP3 | JP4
1 | Not used | Not used | Raw or VCC | Shorts blocking diode
2 TX – remove | to program | RX - remove to program
3 TX – remove | to program | RX - remove to program
4 TX – remove | to program | RX - remove to program | Raw or VCC | Clamp Diodes to Vout

Table 7 - Jumper Settings by Board Revision

4.5.MORE CONNECTION EXAMPLES

Here are a few more buzzer/sounder options.

### 4.5.1. Basic Buzzer

I’ll assume you are using a release 4 board as the JP3 option to bring RAW power (from the wall wart) out to the Vout terminal makes this a little easier. However it is perfectly OK to run your Arduino on a 6V supply and use any voltage up to about 50VDC for the buzzers or sounders, just provide a separate supply and tie the (negative) ground of this supply to the MCBC. Generally a 1A 12VDC regulated wall wart will be more than enough for our purposes.

Once you’ve got your stations programmed, you have to make some decisions about buzzers, and sounders and lights (oh my!). The basic case is to use 12VDC buzzers. These can be driven from the 12 volts on Vout. If they’re not loud enough you can try 5-6 Volt buzzers on the 12V supply, but they may fail prematurely.

Figure 15 - DC Buzzers: available in 6V, 12V and other values

A 12 Volt buzzer of this style will draw about 25mA from 12V, this is well within the 500mA the ULN2803 output Darlingtons will sink, so this will work fine. Be sure to use the

Page 31 | www.modelrailroadcontrolsystems.com | April 14, 2018

clamp diode to ensure that no spikes get onto the 12V power, as that could damage the Arduino.

### 4.5.2. Basic Buzzer with Visual Indicator using an LED

Some layouts have a requirement for a visual indication as well as the audible buzzer, particularly in Yards. An easy enhancement is to put an LED in series with the buzzer. Since the buzzer only draws 25mA and most modern LEDs can handle 30mA, there is no problem; in fact the LED will have a forward voltage drop of 1.5 – 3.5 Volts depending on color, so the actual current will be 20mA +/- 5 mA. You don’t need to put these at every buzzer, just the ones needing a visual indication.

Figure 16 - Basic Visual Indicator with Buzzer

### 4.5.3. What if my Buzzer draws more than 30mA?

Figure 16 works well with buzzer that draw 30mA or less (about 400 ohms or more), but what do you do if you have a buzzer or sounder that draws more than 30mA but is within the 500 mA capacity of the ULN2803 Darlington?

The circuit below works well, and we will be offering it as a “Diode Stack/LED” adapter. The circuit looks like this:

Page 32 | www.modelrailroadcontrolsystems.com | April 14, 2018

Figure 17 - Diode Stack/LED Adapter

What happens is that the 3 Diodes (I recommend using a 1N4004, but any similar Diode capable of 0.5A and with a breakdown voltage of more than your supply will do) each have a forward drop of about 0.7V, so 3 of them will drop a little over 2 Volts. Red, Green, or Yellow LEDs generally turn on at 1.5 – 1.9 V, so the LED sees about 2 volts across itself, but most of the current through the buzzer will pass through the 1N4004 stack. The 22 Ohm resistor is to limit the current through the LED to a safe value of <30mA. For example a Red LED has a forward drop of 1.5V, there’s 2.1 volts total across the diodes, so we’re working with 0.6V. 0.6V/30mA = 20 ohms, our resistor is 22 ohms which is greater than 20, so we’re OK. If you want to use a blue or white LED for an indicator, try using 5 1N4004s in series to get to the forward voltage you need (~3.5V) and connect the LED and resistor across them.

Note that the 2.1 volts your diode stack uses to provide a voltage across your LED means that there is now only 10V (not 12) across your buzzer, so the buzzer may be somewhat less loud. You can use a 15V power supply instead of a 12V supply to make this up.

The Diode Stack/LED has a 4 position connector. The connections are:
- Load
- Anode (+ side of diode)
- Cathode (- side of diode – you can see the “flag” in the diode casting)
- MCBC output

Do not put two diode LED stacks in series. Each station output has its own Diode LED Stack

Page 33 | www.modelrailroadcontrolsystems.com | April 14, 2018

### 4.5.4. I’ve got this really cool old sounder but it draws a lot more than 500mA

across 12 Volts, now what?

Most telegraph sounders on eBay are listed by the DC resistance of the coil. The Darlington outputs on the MCBC can sink up to 500mA, which is 24 ohms at 12V. If your sounder has LESS resistance than 24 ohms, it will draw more than 500 mA and that will damage the ULN2803 (fear not, we socket them and they can be had for about $0.70 from most of the parts houses). One of early users for the MCBC was given a sounder by persons unknown and it turned out to have a coil resistance of 5.5 ohms which works out to a current draw of

### 2.2 A, way more than the ULN 2803 can support. Essentially we needed an amplifier which

can take a smaller signal from the MCBC as a control turn on and sink more current. That’s what we did and we’ll be offering it as a “Sounder Driver” but you can make your own, too. [A quick check as I wrote this (April 2018) shows sounders on eBay with resistances from 4 ohms (3A) up. Prices range from about $40 to $400 depending on vintage, manufacturer and what it’s combined with.] Also see the link Dave Adams provided on the MCBC product page on our web site for instructions on how to make your own sounder.

Figure 18 - Sounder Driver Schematic

The Sounder Driver consists of an inverter (small signal transistor to flip polarity) and a Field Effect Transistor (FET) which can handle 12 Amps, more than enough for our purposes. This allows us to drive the sounder without passing excessive current through the MCBC.

### 4.5.1. Connections

The Sounder Driver has a six position terminal:
- + 12
- Sounder +

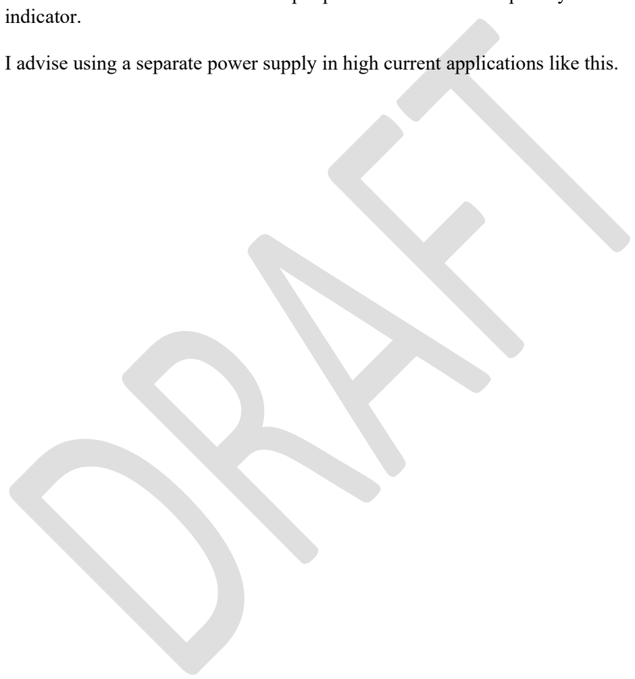
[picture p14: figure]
indicator.

Page 34 | www.modelrailroadcontrolsystems.com | April 14, 2018
- Sounder –
- To All Diode Stack LED boards
- Ground
- Ground

Note that the high current (<12A) path in green goes directly from the sounder to ground and only a small signal “Stacks” goes through the MCBC, so a diode stack is not strictly required but the 3 1N4004 (D1-3) bring the base of Q1 up so they can be used. You can just use a series LED between the MCBC output pin and the “Stacks” input if you want a visual

I advise using a separate power supply in high current applications like this.

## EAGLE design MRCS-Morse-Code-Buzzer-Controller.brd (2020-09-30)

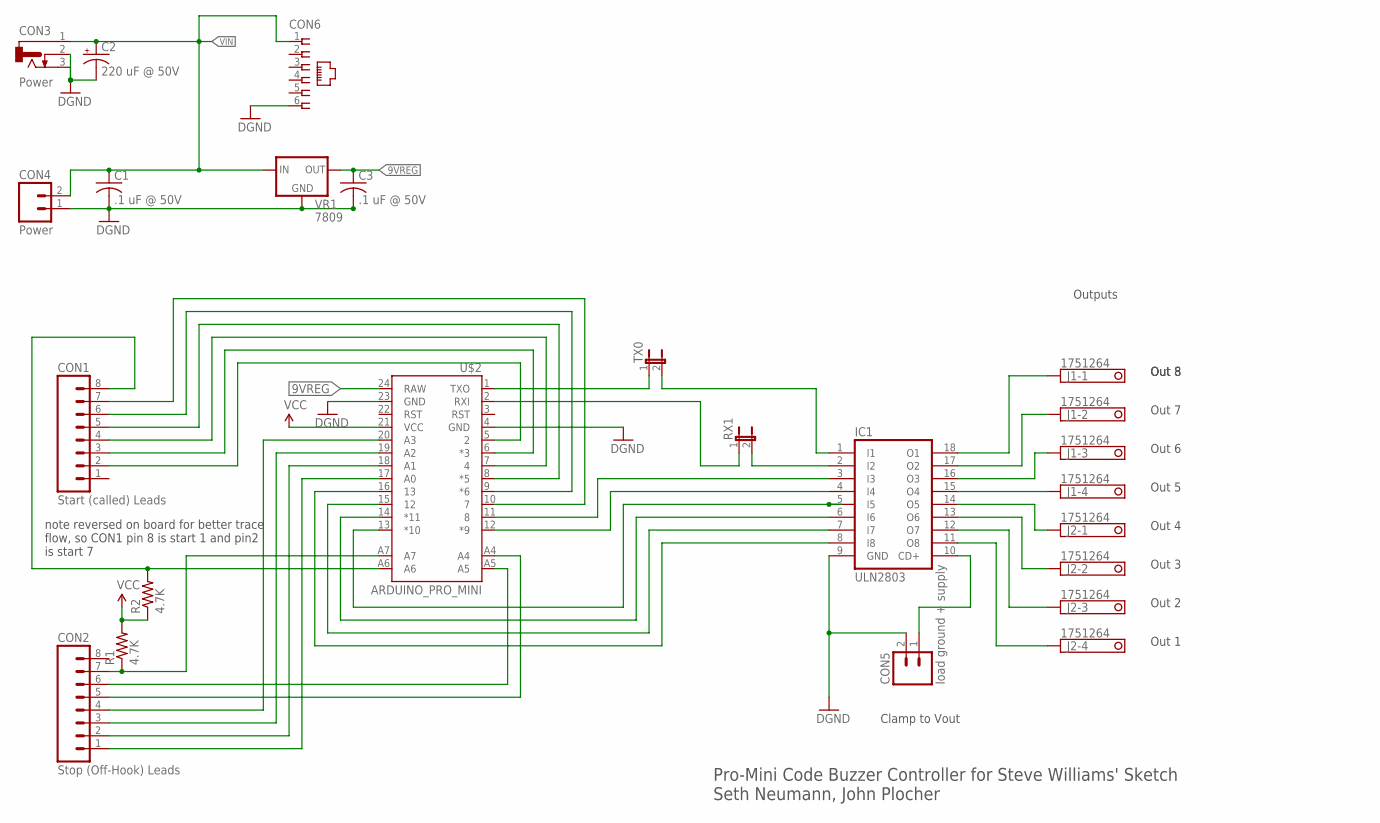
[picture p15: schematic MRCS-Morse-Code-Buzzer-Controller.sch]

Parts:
C1, C3: .1 uF @ 50V; C025-030X050
C2: 220 uF @ 50V; E3,5-10
CON1: Start (called) Leads; 1X08_LOCK
CON2: Stop (Off-Hook) Leads; 1X08_LOCK
CON3: Power; DCJ0202
CON4: Power; MSTB2
CON5: load ground + supply; MSTB2
CON6: CONNECTOR-RJ25-43860-2-MOLEX; RJ25-INVERTED
IC1: ULN2803; DIL18
J1, J2: 1751264
R1, R2: 4.7K; AXIAL-0.4-RES
RX1: JUMPER-2PTH; 1X02
TX0: JUMPER-2PTH; 1X02
U$2: ARDUINO_PRO_MINI
VR1: 7809; TO-220-RA-SINK

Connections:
9VREG: C3.1, U$2.24 (RAW), VR1.OUT
GND: C1.2, C2.-, C3.2, CON3.2, CON3.3, CON4.1, CON5.2, CON6.6, IC1.9 (GND), U$2.4 (GND), U$2.23 (GND), VR1.GND
unnamed: IC1.18 (O1), J1.1
unnamed: IC1.17 (O2), J1.2
unnamed: IC1.16 (O3), J1.3
unnamed: IC1.15 (O4), J1.4
unnamed: IC1.14 (O5), J2.1
unnamed: IC1.13 (O6), J2.2
unnamed: IC1.12 (O7), J2.3
unnamed: IC1.11 (O8), J2.4
unnamed: CON1.2, U$2.5 (2)
unnamed: CON1.3, U$2.6 (*3)
unnamed: CON1.4, U$2.7 (4)
unnamed: CON1.5, U$2.8 (*5)
unnamed: CON1.6, U$2.9 (*6)
unnamed: CON1.7, U$2.10 (7)
unnamed: CON1.8, R2.P$2 (2), U$2.A6
unnamed: CON2.7, R1.P$1 (1), U$2.A7
unnamed: CON2.1, U$2.17 (A0)
unnamed: IC1.3 (I3), U$2.11 (8)
unnamed: IC1.4 (I4), U$2.12 (*9)
unnamed: IC1.8 (I8), U$2.16 (13)
unnamed: IC1.5 (I5), U$2.13 (*10)
unnamed: IC1.6 (I6), U$2.14 (*11)
unnamed: IC1.7 (I7), U$2.15 (12)
unnamed: CON2.2, U$2.18 (A1)
unnamed: CON2.3, U$2.19 (A2)
unnamed: CON2.4, U$2.20 (A3)
unnamed: CON2.5, U$2.A4
unnamed: CON2.6, U$2.A5
unnamed: TX0.1, U$2.1 (TXO)
unnamed: IC1.1 (I1), TX0.2
unnamed: IC1.2 (I2), RX1.2
unnamed: CON5.1, IC1.10 (CD+)
unnamed: RX1.1, U$2.2 (RXI)
VCC: R1.P$2 (2), R2.P$1 (1), U$2.21 (VCC)
VIN: C1.1, C2.+, CON3.1, CON4.2, CON6.1, VR1.IN

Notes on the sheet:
Pro-Mini Code Buzzer Controller for Steve Williams' Sketch Seth Neumann, John Plocher
Outputs
Out 8
Out 7
Out 6
Out 5
Out 4
Out 3
Out 2
Out 1
note reversed on board for better trace flow, so CON1 pin 8 is start 1 and pin2 is start 7
Clamp to Vout

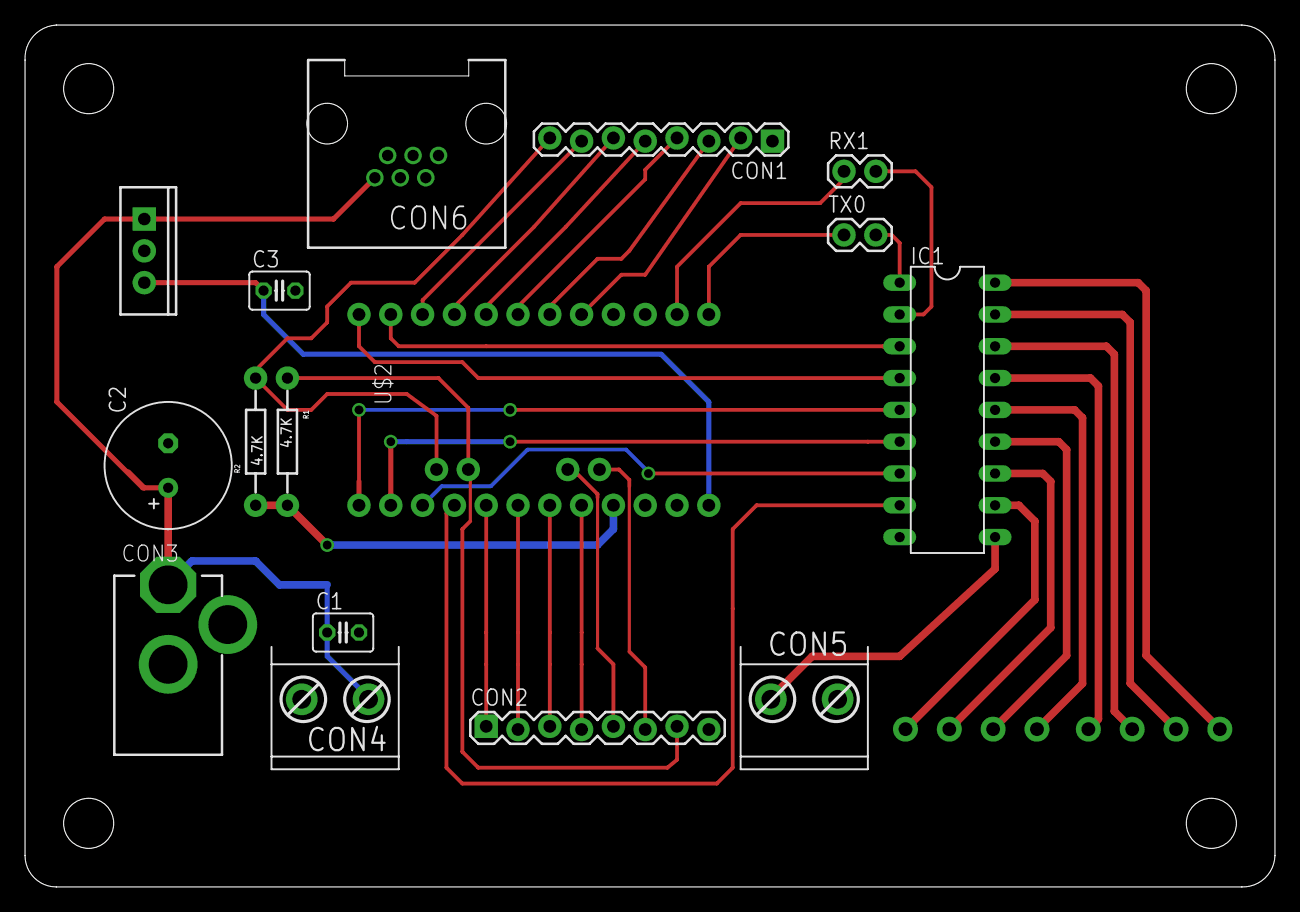
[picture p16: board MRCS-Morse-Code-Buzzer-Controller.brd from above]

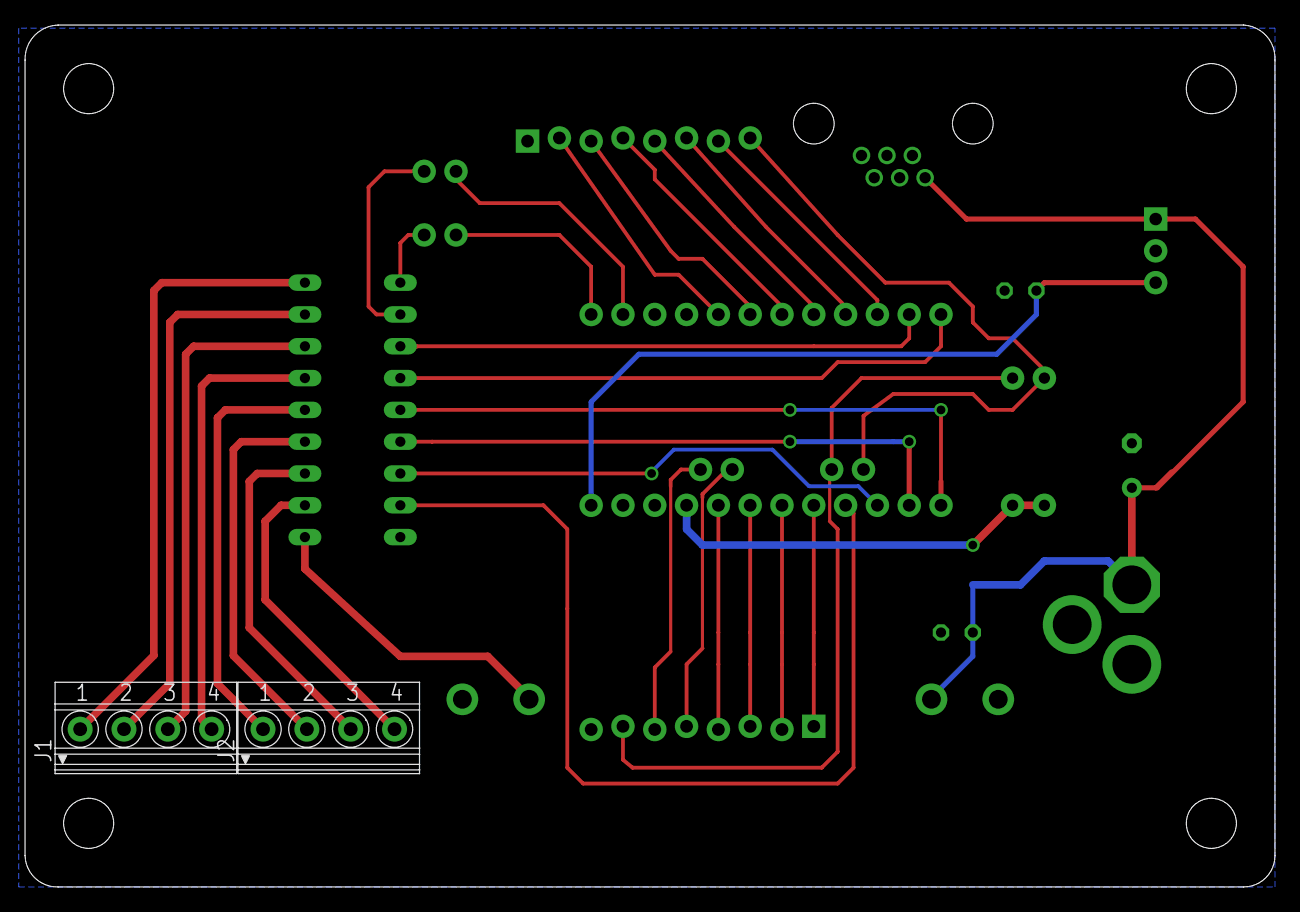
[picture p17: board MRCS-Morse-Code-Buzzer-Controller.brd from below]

Board: 2 copper layers, 99.8 x 68.8 mm, 20 parts (2 on the bottom side), 37 nets.

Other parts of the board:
U$1: BOARD-DINRAIL-2.71IN-MRCS
U$3: CA-PROP65WARNING

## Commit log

2020-09-30 sent to fab
    sent to fab
    [MRCS-Morse-Code-Buzzer-Controller.brd, MRCS-Morse-Code-Buzzer-Controller.sch]
2020-10-01 deleted dummy entries
    deleted dummy entries
    [EagleTemplate-new.brd, EagleTemplate-new.sch]
2025-04-17 Create Morse Code Buzzer Controller Assembly and Installation.pdf
    Assembly and installation instructions. Apparently I never added this to the file.

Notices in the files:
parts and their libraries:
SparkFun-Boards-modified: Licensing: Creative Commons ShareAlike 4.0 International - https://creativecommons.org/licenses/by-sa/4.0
